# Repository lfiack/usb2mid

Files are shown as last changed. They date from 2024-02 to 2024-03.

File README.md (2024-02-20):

# usb2mid
Small USB to MIDI bridge

## Make the project work
This project uses a submodule for the KiCAD library. To get it properly, use the `--recursive` option when cloning the repo :

```bash
git clone --recursive git@github.com:lfiack/usb2mid.git
```

If you forgot the `--recursive` option (as I do quite often), you can type the following command :

```bash
git submodule update --init --recursive
```

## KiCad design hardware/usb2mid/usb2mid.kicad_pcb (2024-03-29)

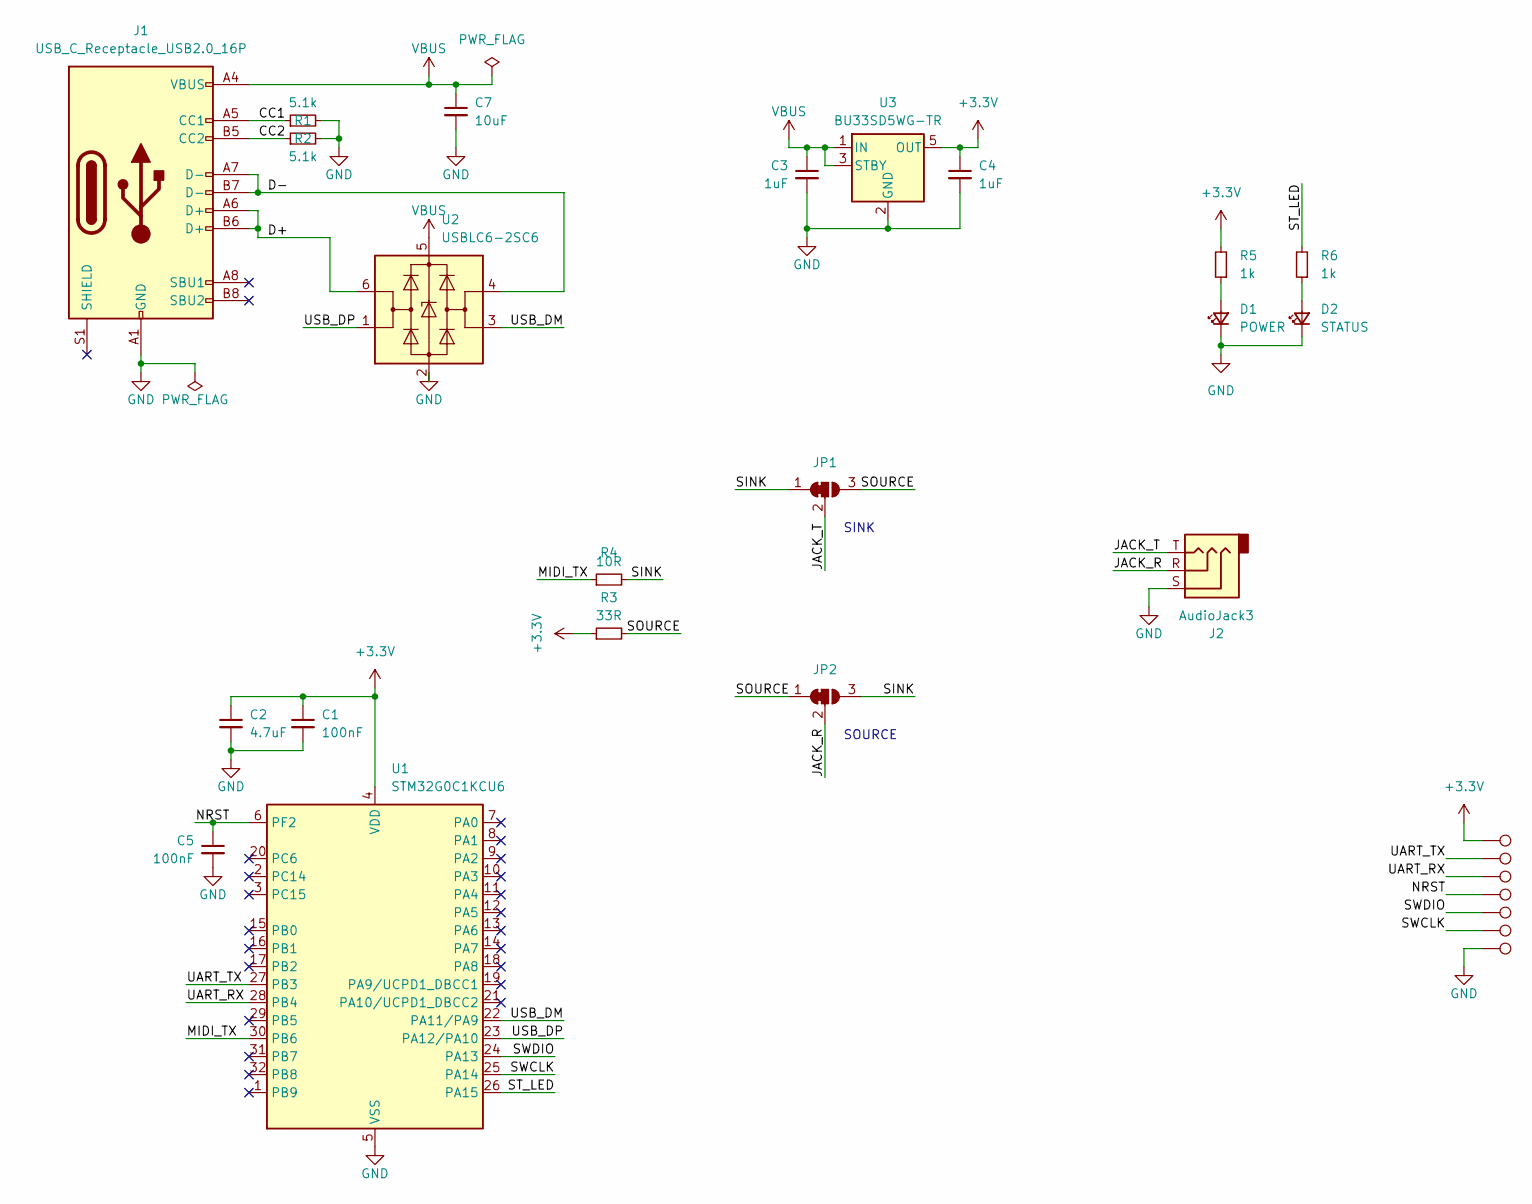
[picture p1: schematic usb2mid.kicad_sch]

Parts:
C1, C5: 100nF; C_0402_1005Metric
C2: 4.7uF; C_0603_1608Metric
C3, C4: 1uF; C_0402_1005Metric
C7: 10uF; C_0603_1608Metric
D1: POWER; LED_0603_1608Metric
D2: STATUS; LED_0603_1608Metric
J1: USB_C_Receptacle_USB2.0_16P; USB_C_Receptacle_GCT_USB4105-xx-A_16P_TopMnt_Horizontal
J2: AudioJack3; Jack_3.5mm_CUI_SJ-3523-SMT_Horizontal; Mouser 490-SJ-3523-SMT-TR
JP1, JP2: SolderJumper_3_Bridged12; SolderJumper-3_P1.3mm_Bridged12_RoundedPad1.0x1.5mm
R1, R2: 5.1k; R_0402_1005Metric
R3: 33R; R_0805_2012Metric
R4: 10R; R_0805_2012Metric
R5, R6: 1k; R_0603_1608Metric
TP1, TP2, TP3, TP4, TP5, TP6, TP7: TestPoint; TestPoint_Pad_D1.0mm
U1: STM32G0C1KCU6; QFN-32-1EP_5x5mm_P0.5mm_EP3.45x3.45mm; Mouser 511-STM32G0C1KCU6
U2: USBLC6-2SC6; SOT-23-6
U3: BU33SD5WG-TR; SOT-23-5

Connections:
+3.3V: C1.1, C2.1, C4.1, R3.1, R5.2, TP7.1, U1.4 (VDD), U3.5 (OUT)
/CC1: J1.A5 (CC1), R1.1
/CC2: J1.B5 (CC2), R2.1
/D+: J1.A6 (D+), J1.B6 (D+), U2.6 (I/O1)
/D-: J1.A7 (D-), J1.B7 (D-), U2.4 (I/O2)
/JACK_R: J2.R, JP2.2 (C)
/JACK_T: J2.T, JP1.2 (C)
/MIDI_TX: R4.1, U1.30 (PB6)
/NRST: C5.1, TP3.1, U1.6 (PF2)
/SINK: JP1.1 (A), JP2.3 (B), R4.2
/SOURCE: JP1.3 (B), JP2.1 (A), R3.2
/ST_LED: R6.2, U1.26 (PA15)
/SWCLK: TP5.1, U1.25 (PA14)
/SWDIO: TP4.1, U1.24 (PA13)
/UART_RX: TP2.1, U1.28 (PB4)
/UART_TX: TP1.1, U1.27 (PB3)
/USB_DM: U1.22 (PA11/PA9), U2.3 (I/O2)
/USB_DP: U1.23 (PA12/PA10), U2.1 (I/O1)
GND: C1.2, C2.2, C3.2, C4.2, C5.2, C7.2, D1.1 (K), D2.1 (K), J1.A1 (GND), J1.A12 (GND), J1.B1 (GND), J1.B12 (GND), J2.S, R1.2, R2.2, TP6.1, U1.5 (VSS), U1.33 (VSS), U2.2 (GND), U3.2 (GND)
unnamed: D1.2 (A), R5.1
unnamed: D2.2 (A), R6.1
VBUS: C3.1, C7.1, J1.A4 (VBUS), J1.A9 (VBUS), J1.B4 (VBUS), J1.B9 (VBUS), U2.5 (VBUS), U3.1 (IN), U3.3 (STBY)

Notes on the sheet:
SOURCE
SINK

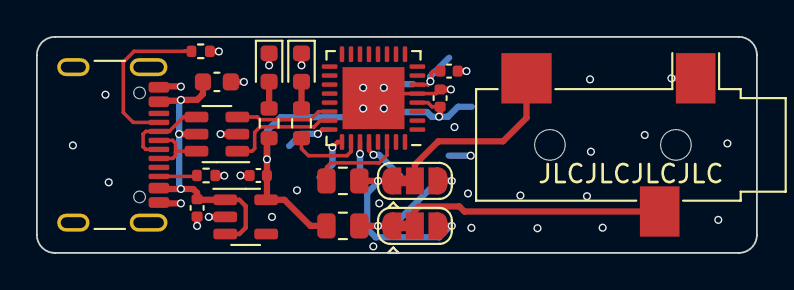
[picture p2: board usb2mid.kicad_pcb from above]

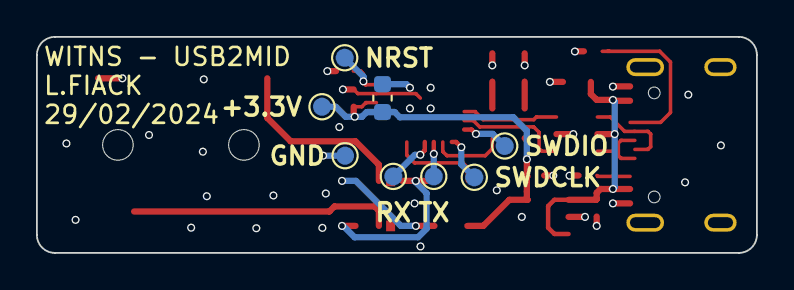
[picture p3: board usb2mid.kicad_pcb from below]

Board: 4 copper layers, 40.0 x 12.0 mm, 28 parts (8 on the bottom side), 22 nets.

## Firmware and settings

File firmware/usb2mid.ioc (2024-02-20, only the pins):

Mcu.UserName=STM32G0C1KCUx
PA13.Signal=SYS_SWDIO
PA14-BOOT0.Signal=SYS_SWCLK
PA15.GPIO_Label=ST_LED
PA15.Signal=GPIO_Output
PB3.Signal=USART5_TX
PB4.Signal=USART5_RX
PB6.Signal=USART1_TX
PB7.Signal=USART1_RX

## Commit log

2024-02-20 first pcb
    [usb2mid.kicad_pcb, usb2mid.kicad_sch]
2024-02-29 minor corrections + gerber
    [usb2mid-B_Cu.gbr, usb2mid-B_Mask.gbr, usb2mid-B_Paste.gbr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]
2024-03-12 changed USB-C footprint
    [usb2mid.kicad_pcb, usb2mid.kicad_sch]
2024-03-28 oops USB ESD!!
    [usb2mid.kicad_pcb, usb2mid.kicad_sch]
2024-03-29 minor corrections to PCB
    [usb2mid-B_Cu.gbr, usb2mid-B_Mask.gbr, usb2mid-B_Paste.gbr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]
2024-03-29 solder paste clearance 10%
    [usb2mid-B_Cu.gbr, usb2mid-B_Mask.gbr, usb2mid-B_Paste.gbr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]
